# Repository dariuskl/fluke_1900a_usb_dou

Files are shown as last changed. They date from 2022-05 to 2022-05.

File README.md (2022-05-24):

# PCB

The latest PCB revision that has been produced and tested is rev. 0. However,
there is an error in that version: Rx and Tx are swapped (of course!) on the
USB side. That can be fixed with a bodge, but later commits fix that mistake
without making functional changes.

# Firmware

The latest firmware version that has been tested is 0.1.0.0. There are no known
issues.

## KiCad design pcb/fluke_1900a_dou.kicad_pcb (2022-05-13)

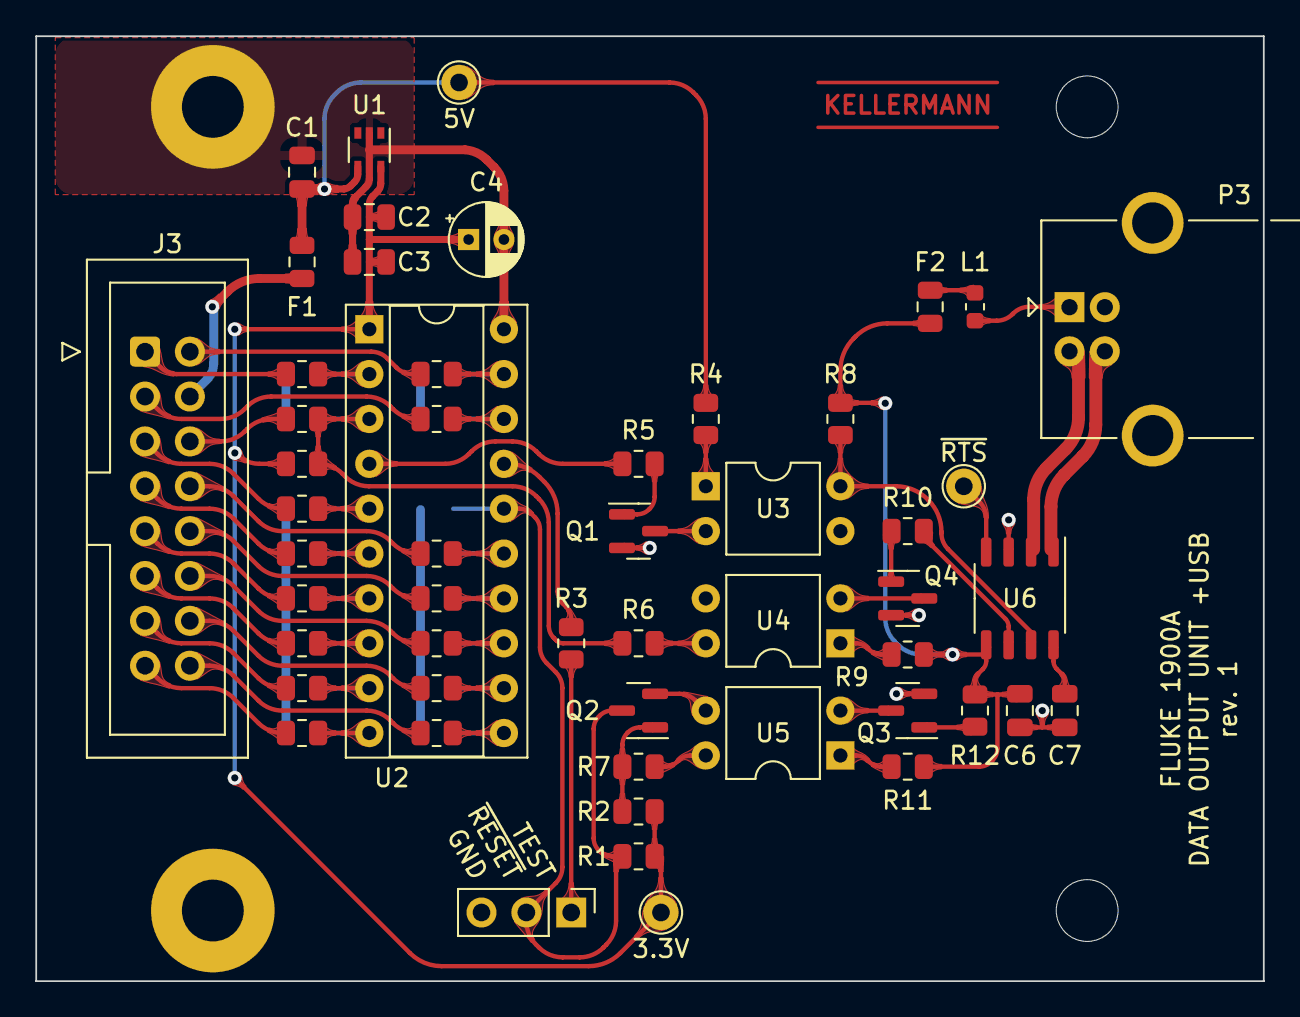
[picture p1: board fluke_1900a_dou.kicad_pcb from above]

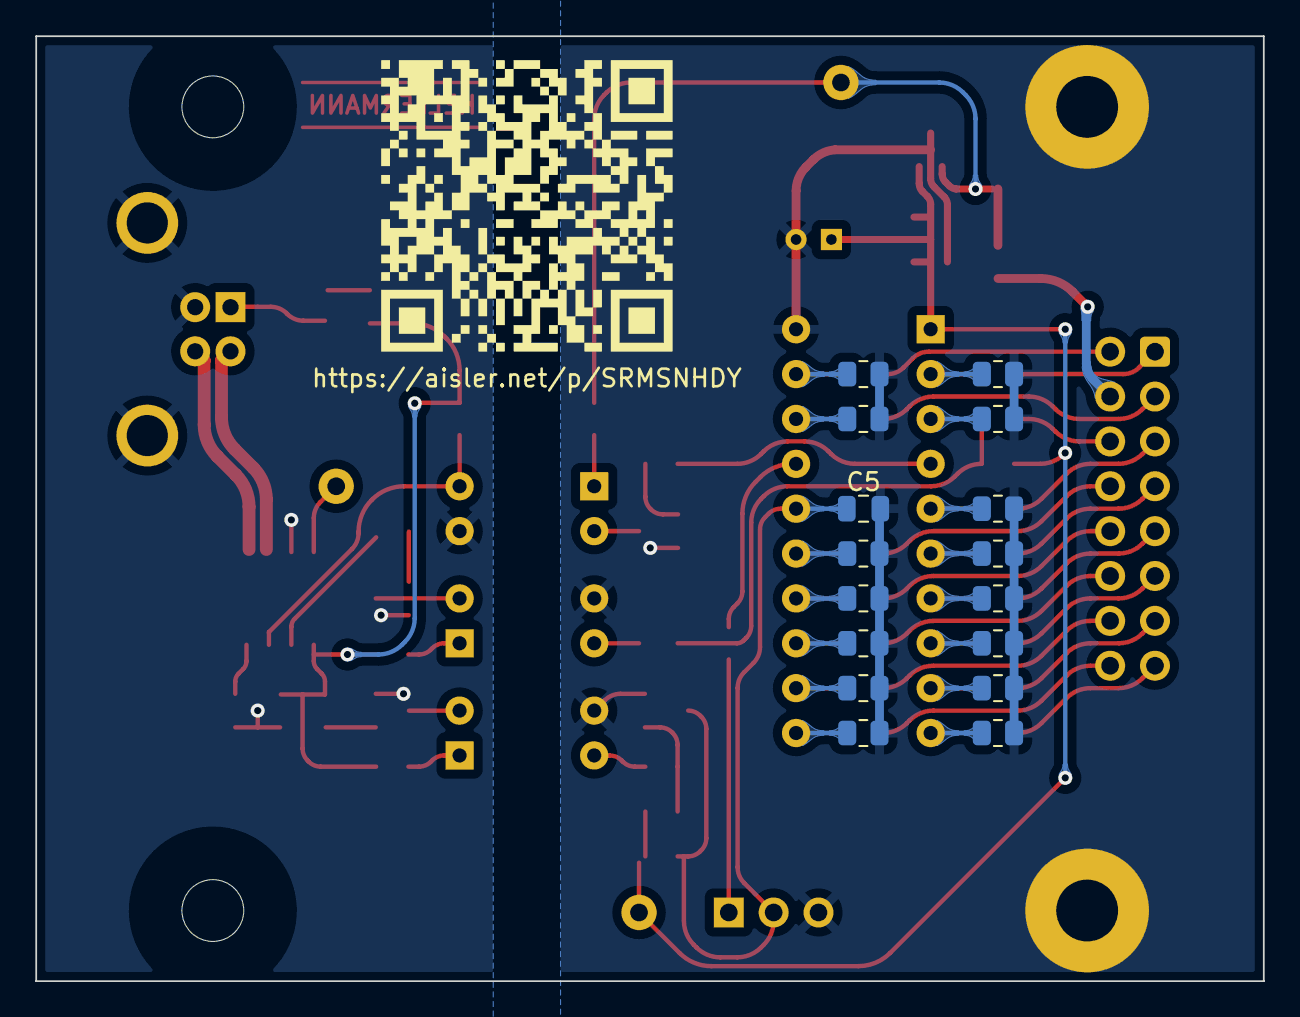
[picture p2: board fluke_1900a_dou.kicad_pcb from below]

Board: 2 copper layers, 69.5 x 53.5 mm, 74 parts (17 on the bottom side), 60 nets.

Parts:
C1, C3, C6, C7: 100n; C_0805_2012Metric
C2: 470n; C_0805_2012Metric
C4: 10u/10V; CP_Radial_D4.0mm_P2.00mm
C5: 2.2nF 0805; C_0805_2012Metric
F1, F2: 100mA 0805; Fuse_0805_2012Metric
H1, H2: 3,5mm; MountingHole_3.5mm_Pad
H3, H4: 3,5mm; MountingHole_3.5mm
J3: DOU CONNECTOR; IDC-Header_2x08_P2.54mm_Vertical
L1: 600R 1A 0603; L_0603_1608Metric
P3: USB_B; USB_B_OST_USB-B1HSxx_Horizontal
Q1, Q2, Q3, Q4: Si2336DS; SOT-23
QR1: https://aisler.net/p/SRMSNHDY; Aisler_QR
R1: 47k; R_0805_2012Metric
R2: 100k; R_0805_2012Metric
R3: 330; R_0805_2012Metric
R4, R9, R11: 390R 0805; R_0805_2012Metric
R5, R6, R7, R10, R12: 0; R_0805_2012Metric
R8: 4k7; R_0805_2012Metric
R13: DNP; R_0805_2012Metric
R20, R21, R22, R24, R25, R26, R27, R28, R29, R30, R31, R32, R33, R34, R35, R36, R37, R38, R39, R40, R41, R42, R43, R44, R45, R46, R47, R48, R49, R50: 1.2M 0805; R_0805_2012Metric
TP1: 5V; TestPoint_THTPad_D2.0mm_Drill1.0mm
TP2: 3.3V; TestPoint_THTPad_D2.0mm_Drill1.0mm
TP3: ~{RTS}; TestPoint_THTPad_D2.0mm_Drill1.0mm
U1: TPS71533; SOT-353_SC-70-5
U2: MSP430G2452IN20; DIP-20_W7.62mm_Socket
U3, U4, U5: SFH617A-4; DIP-4_W7.62mm
U6: CH340N; SOP-8_3.9x4.9mm_P1.27mm
X1: DEBUG; PinHeader_1x03_P2.54mm_Vertical

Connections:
+3V3: C2.1, C3.1, C4.1, R1.2, R2.2, R13.1, TP2.1, U1.5 (OUT), U2.1 (DVCC)
+5V: C1.1, F1.1, R4.1, TP1.1, U1.4 (IN)
/AS_1: R6.2, R13.2, R25.1, R45.1, U2.3 (TA0.0/CA1/A1/P1.1)
/AS_2: R27.1, R46.1, U2.15 (TDO/TDI/SDI/SDA/CAOUT/CA7/A7/P1.7)
/AS_3: R29.1, R47.1, U2.14 (TDI/TCLK/TA0.1/SDO/SCL/CA6/A6/P1.6)
/AS_4: R31.1, R48.1, U2.13 (P2.5)
/AS_5: R33.1, R49.1, U2.12 (P2.4)
/AS_6: R35.1, R50.1, U2.11 (P2.3)
/D+: P3.3 (D+), U6.1 (UD+)
/D-: P3.2 (D-), U6.2 (UD-)
/DS: R22.1, R42.1, U2.18 (P2.7/XOUT)
/OUT_A: R21.1, R44.1, U2.19 (P2.6/XIN/TA0.1)
/OUT_B: R20.2, R43.1, U2.2 (TA0CLK/ACLK/CA0/A0/P1.0)
/OUT_C: R32.2, R37.1, U2.9 (P2.1)
/OUT_D: R34.2, R36.1, U2.10 (P2.2)
/OVFL: R28.2, R39.1, U2.7 (TMS/SCLK/TA0.0/CA5/A5/P1.5)
/RESET: Q2.1 (G), R2.1, R7.2
/RNG_2: R24.2, R41.1, U2.5 (ADC10CLK/VREF-/VeREF-/CAOUT/CA3/A3/P1.3)
/RXD: R8.1, U3.4, U6.7 (RXD)
/Rx: R6.1, U4.4
/SBWTCK: R3.2, X1.1
/TXD: R10.1, U6.6 (TXD)
/Tx: R5.1, U2.4 (TA0.1/CA2/A2/P1.2)
/~ML: R26.2, R40.1, U2.6 (TCK/SMCLK/TA0.2/VREF+/VeREF+/CA4/A4/P1.4)
/~MUP: R30.2, R38.1, U2.8 (P2.0)
/~RESET: C5.1, Q2.3 (D), R1.1, U2.16 (~RST/NMI/SBWTDIO), X1.2
GND: C1.2, C2.2, C3.2, C4.2, C5.2, H1.1, H2.1, Q1.2 (S), Q2.2 (S), R36.2, R37.2, R38.2, R39.2, R40.2, R41.2, R42.2, R43.2, R44.2, R45.2, R46.2, R47.2, R48.2, R49.2, R50.2, U1.2 (GND), U2.20 (DVSS), U4.3, U5.3, X1.3
GND1: C6.1, C7.2, P3.4 (GND), P3.5 (Shield), Q3.2 (S), Q4.2 (S), U3.3, U6.3 (GND)
unnamed: C7.1, U6.8 (V3)
unnamed: F1.2, J3.4
unnamed: J3.1, R20.1
unnamed: J3.2, R21.2
unnamed: J3.3, R22.2
unnamed: J3.5, R24.1
unnamed: J3.6, R25.2
unnamed: J3.8, R27.2
unnamed: J3.9, R28.1
unnamed: J3.10, R29.2
unnamed: J3.11, R30.1
unnamed: J3.12, R31.2
unnamed: J3.13, R32.1
unnamed: J3.14, R33.2
unnamed: J3.15, R34.1
unnamed: J3.16, R35.2
unnamed: F2.1, L1.1
unnamed: L1.2, P3.1 (VBUS)
unnamed: Q1.1 (G), R5.2
unnamed: Q1.3 (D), U3.2
unnamed: Q3.1 (G), R12.2
unnamed: Q3.3 (D), U5.2
unnamed: Q4.1 (G), R10.2
unnamed: Q4.3 (D), U4.2
unnamed: R3.1, U2.17 (SBWTCK/TEST)
unnamed: R4.2, U3.1
unnamed: R7.1, U5.4
unnamed: R9.2, U4.1
unnamed: R11.2, U5.1
unnamed: J3.7, R26.1
unnamed: TP3.1, U6.4 (~RTS)
VBUS: C6.2, F2.2, R8.2, R9.1, R11.1, R12.1, U6.5 (VCC)

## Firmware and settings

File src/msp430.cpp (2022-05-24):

// Data Output Unit Firmware / Darius Kellermann <kellermann@protonmail.com>

#include "msp430.hpp"

#include "dou.hpp"
#include "nostd.hpp"

#include <string_view>

namespace dou {

  constexpr auto smclk_frequency_Hz = 16'000'000;

  constexpr auto &tx_port_ = msp430::P1OUT;

  // port 1
  constexpr auto out_b_mask_ = u8{0x01}; // BCD 2
  constexpr auto as_1_mask_ = u8{0x02};  // LSD
  constexpr auto tx_mask_ = u8{0x04};
  constexpr auto rng_2_mask_ = u8{0x08};
  constexpr auto nml_mask_ = u8{0x10};
  constexpr auto ovfl_mask_ = u8{0x20};
  constexpr auto as_3_mask_ = u8{0x40}; // 4SD
  constexpr auto as_2_mask_ = u8{0x80}; // 5SD

  // port 2
  constexpr auto nmup_mask_ = u8{0x01};
  constexpr auto out_c_mask_ = u8{0x02}; // BCD 4
  constexpr auto out_d_mask_ = u8{0x04}; // BCD 8
  constexpr auto as_6_mask_ = u8{0x08};  // MSD
  constexpr auto as_5_mask_ = u8{0x10};  // 2SD
  constexpr auto as_4_mask_ = u8{0x20};  // 3SD
  constexpr auto out_a_mask_ = u8{0x40}; // BCD 1
  constexpr auto ds_mask_ = u8{0x80};

  Input_state decode_signals(const u8 port1, const u8 port2) {
    return {
        static_cast<i8>(
            ((port1 & as_1_mask_) != u8{0})
                ? 1
                : (((port1 & as_2_mask_) != u8{0})
                       ? 2
                       : (((port1 & as_3_mask_) != u8{0})
                              ? 3
                              : (((port2 & as_4_mask_) != u8{0})
                                     ? 4
                                     : (((port2 & as_5_mask_) != u8{0})
                                            ? 5
                                            : (((port2 & as_6_mask_) != u8{0})
                                                   ? 6
                                                   : 0)))))),
        static_cast<i8>((((port2 & out_a_mask_) != u8{0}) ? u8{1} : u8{0})
                        | (((port1 & out_b_mask_) != u8{0}) ? u8{2} : u8{0})
                        | (((port2 & out_c_mask_) != u8{0}) ? u8{4} : u8{0})
                        | (((port2 & out_d_mask_) != u8{0}) ? u8{8} : u8{0})),
        (port2 & ds_mask_) != u8{0},
        (port1 & ovfl_mask_) != u8{0},
        (port1 & nml_mask_) != u8{0},
        (port1 & rng_2_mask_) != u8{0}};
  }

  namespace {
    auto serial = Serial_transmitter{};
    auto decoder = Bus_decoder{};
  } // namespace

  void enable_nmup_interrupt() { store(msp430::P2IE, u8{nmup_mask_}); }
  void disable_nmup_interrupt() { store(msp430::P2IE, u8{0}); }

  [[noreturn]] void run() {
    // Clear P2SEL reasonably early, because excess current will flow from
    // the oscillator driver output at P2.7.
    store(msp430::P2SEL, u8{0});

    // The watchdog timer will reset the device, if no nMUP signal has been
    // detected after expiration of the longest gate time of 10 seconds.
    msp430::Watchdog_timer::hold(); // TODO set up watchdog

    store(msp430::BCSCTL1, load(msp430::CAL_BC1_16MHz));
    store(msp430::DCOCTL, load(msp430::CAL_DCO_16MHz));
    store(msp430::BCSCTL3, u8{0x24}); // ACLK=VLOCLK

    store(msp430::P1OUT, u8{0});
    store(msp430::P1DIR, tx_mask_);
    store(msp430::P1IES, u8{0});
    store(msp430::P1REN, u8{0});
    store(msp430::P2DIR, u8{0});
    store(msp430::P2IES, u8{nmup_mask_});
    store(msp430::P2IE, u8{nmup_mask_});
    store(msp430::P2REN, u8{0});

    auto uart_timer = msp430::Timer0_A3{msp430::Timer_A_clock_source::SMCLK, 1};
    uart_timer.enable_interrupt();

    msp430::enable_interrupts();

    msp430::go_to_sleep();

    while (true) {
      const auto port1 = load(msp430::P1IN);
      const auto port2 = load(msp430::P2IN);

      const auto update_memory = (port2 & nmup_mask_) == u8{0};

      const auto input_state = decode_signals(port1, port2);

      if (update_memory) {
        decoder.transit(input_state);
      } else {
        disable_nmup_interrupt();

        const auto buffer = std::string_view{decoder.reading()};

        uart_timer.start_up(u16{(smclk_frequency_Hz / serial_baud_rate) - 1});

        for (const auto& character : buffer) {
          serial.init_transmission(character);
          auto bit = u8{0};
          while (serial.get_next_bit(bit)) {
            // Wait for the first and next bit.
            msp430::go_to_sleep();
            store(tx_port_, (load(tx_port_) & ~tx_mask_)
                                | (bit != u8{0} ? u8{0} : tx_mask_));
          }
          // Wait for the last bit.
          msp430::go_to_sleep();
          store(tx_port_, load(tx_port_) & ~tx_mask_);
        }
        uart_timer.stop();
        decoder = {};

        // Wait for a falling edge on /MUP.
        enable_nmup_interrupt();
        msp430::go_to_sleep();
      }
    }
  }

  namespace {

    /// Called on falling edge on /MUP.
    [[gnu::interrupt]] void on_strobe() {
      store(msp430::P2IFG, u8{0});
      msp430::stay_awake();
    }

    [[gnu::interrupt]] void on_timer() { msp430::stay_awake(); }

    extern "C" [[noreturn, gnu::naked]] void on_reset() {
      // init stack pointer
      extern const uint16_t _stack;
      asm volatile("mov %0, SP" : : "ri"(&_stack));

      // .data
      extern uint16_t _sdata[];        // .data start
      extern uint16_t _edata;          // .data end
      extern const uint16_t _sidata[]; // .data init values
      const auto data_count = &_edata - &(_sdata[0]);
      for (auto i = 0; i < data_count; ++i) {
        _sdata[i] = _sidata[i];
      }

      // .bss
      extern uint16_t _sbss[]; // .bss start
      extern uint16_t _ebss;   // .bss end
      const auto bss_count = &_ebss - &(_sbss[0]);
      for (auto i = 0; i < bss_count; ++i) {
        _sbss[i] = 0U;
      }

      // .preinit_array
      extern void (*_preinit_array_start[])();
      extern void (*_preinit_array_end[])();
      const auto num_preinits = &(_preinit_array_end[0])
                                - &(_preinit_array_start[0]);
      for (auto i = 0; i < num_preinits; ++i) {
        _preinit_array_start[i]();
      }

      // .init_array
      extern void (*_init_array_start[])();
      extern void (*_init_array_end[])();
      const auto num_inits = &(_init_array_end[0]) - &(_init_array_start[0]);
      for (auto i = 0; i < num_inits; ++i) {
        _init_array_start[i]();
      }

      run();
    }

    [[gnu::interrupt]] void default_isr() {}

    constexpr auto vtable_
        [[gnu::used, gnu::section(".vectors")]] = Array<void (*)(), 32>{
            {nullptr,     nullptr,   nullptr,     nullptr,     nullptr, nullptr,
             nullptr,     nullptr,   nullptr,     nullptr,     nullptr, nullptr,
             nullptr,     nullptr,   nullptr,     nullptr,     nullptr, nullptr,
             on_strobe,   on_strobe, default_isr, default_isr, nullptr, nullptr,
             default_isr, on_timer,  default_isr, default_isr, nullptr, nullptr,
             default_isr, on_reset}};

  } // namespace

} // namespace dou

int main() { dou::run(); }

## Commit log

2022-05-02 initial revision of the PCB finished and ordered
    [fluke_1900a_dou.kicad_pcb, fluke_1900a_dou.kicad_sch]
2022-05-03 Tx must be connected to RXD on the CH340N
    [fluke_1900a_dou.kicad_pcb, fluke_1900a_dou.kicad_sch]
2022-05-03 add fuses F1, F2 to protect device and USB host
    In case in anything ever does go wrong, the fuse should protect the
    device from any harm. The same makes sense for the USB side of things.
    [fluke_1900a_dou.kicad_pcb, fluke_1900a_dou.kicad_sch]
2022-05-03 add pull-up R13 to Rx line
    While the Rx line is currently not usable, it should be able to operate
    at the same bitrate as the Tx line. That requires the ability to select
    the pull-up accordingly.
    [fluke_1900a_dou.kicad_pcb, fluke_1900a_dou.kicad_sch]
2022-05-13 put a comment regarding mounting
    [fluke_1900a_dou.kicad_pcb]
2022-05-24 add documentation for title block and various components
    [fluke_1900a_dou.kicad_sch]
